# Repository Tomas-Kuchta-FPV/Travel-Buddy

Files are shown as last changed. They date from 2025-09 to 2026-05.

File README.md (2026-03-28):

# Travel-Buddy
Pocketable, smart and sleek Meshtastic node. With keyboard, Eink screen, GPS and all day baterry life thanks to it's Solar panel. Based on the [Seed Studio Wio tracker L1](https://meshtastic.org/docs/hardware/devices/seeed-studio/wio-series/tracker-l1/).  

Took inspiration from the original idea of Meshtastic and made a hiker, prepper and EDC friendly device.  

## Specifications
- **Wio tracker L1 Eink** a nifty main board
    - **GPS** to know where you and your frinds are
    - **nRF52840** to sip power bit by bit
    - **2.3 Inch Eink screen** so you never miss anything 
    - **Navigation buttons** for easy and intuitive control
    - **On-Off button** to save power for when the Sun is hiding
    - **Antenna** the default antenna is pretty good
- [3x4 Nokia style](https://en.wikipedia.org/wiki/T9_%28predictive_text%29) keyboard for easy texting
- **Solar panel** so your battery can be rechargerd from 0 to 100 in just two daays
- Space for a **big battery** for the days when the sun isn't shining

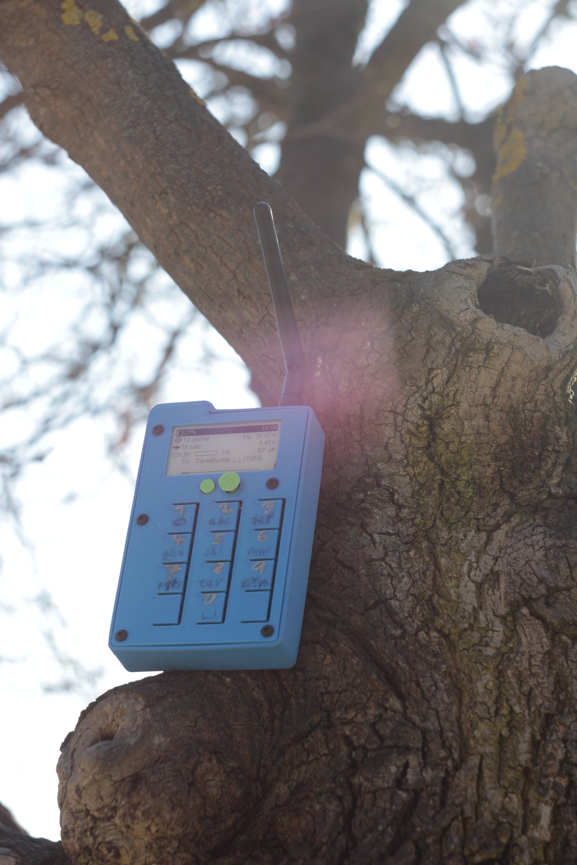
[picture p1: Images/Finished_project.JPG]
Finished Project


| Front | Back |
| --- | --- |
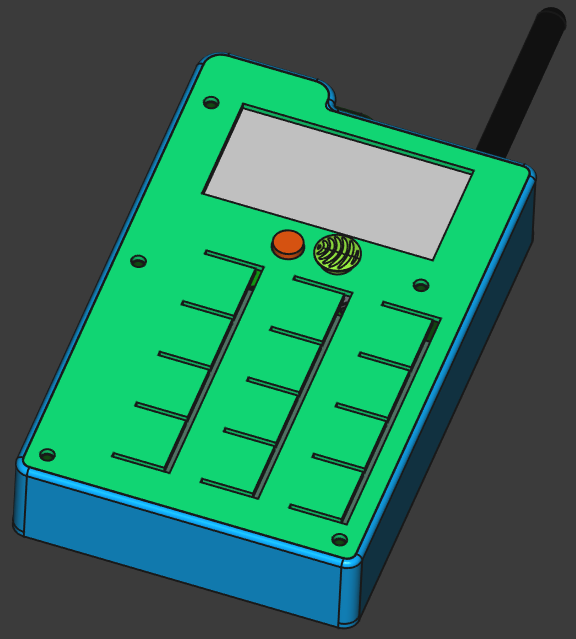
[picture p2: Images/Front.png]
front
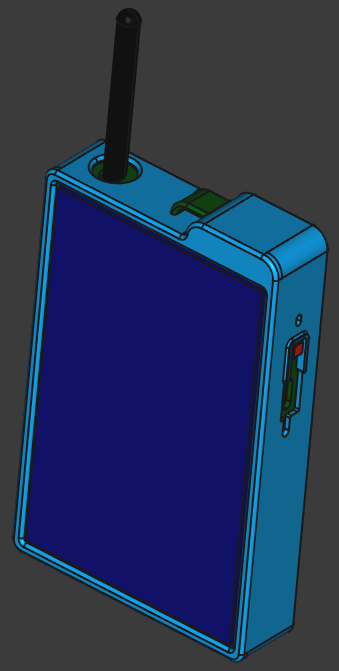
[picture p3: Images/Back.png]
back
|  |  |

## Use cases
Built for hikers, makers, preppers, and everyday carry adventurers who like their tech smart, tough, and a little bit magical.

**Hikers** can wander freely without worrying about battery life, coverage, or fragile screens. Solar charging keeps it alive on long trails, GPS keeps you oriented, and Meshtastic keeps you connected with your group even when civilization politely vanishes. The only real responsibility is remembering to bring it along. 😅

**Makers** will feel right at home. It’s open-source, hackable, and begging to be customized. New firmware ideas, experimental features, clever power optimizations. This thing is a playground for curious minds who like to bend hardware to their will.

**Preppers** get a resilient, low-power communication tool that keeps working when the grid doesn’t. Solar charging, long battery life, offline mesh networking, and the ability to tinker and repair make it a quiet little survival ally that doesn’t ask for much.

**EDC** enthusiasts get a pocketable device that just works. No constant charging anxiety, no fragile glass screens, no babysitting. Toss it in your bag or clip it to your gear and let it quietly do its job, day after day, powered by sunlight and good engineering dreams.

| Top | Front | PCB |
| --- | --- | --- |
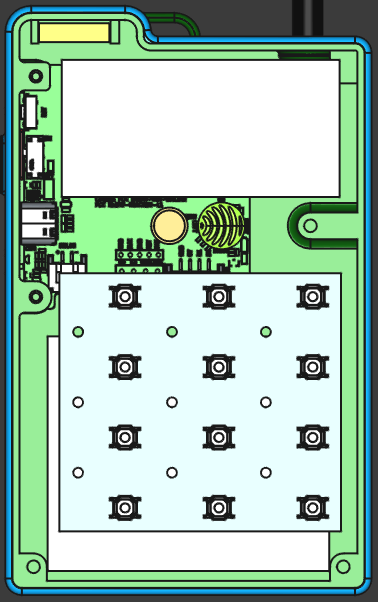
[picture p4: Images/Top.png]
Top
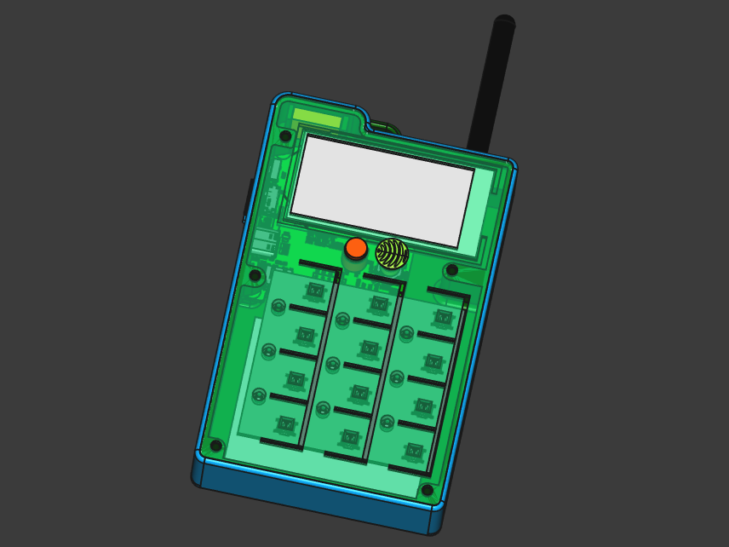
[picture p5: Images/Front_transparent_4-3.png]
Front_trans
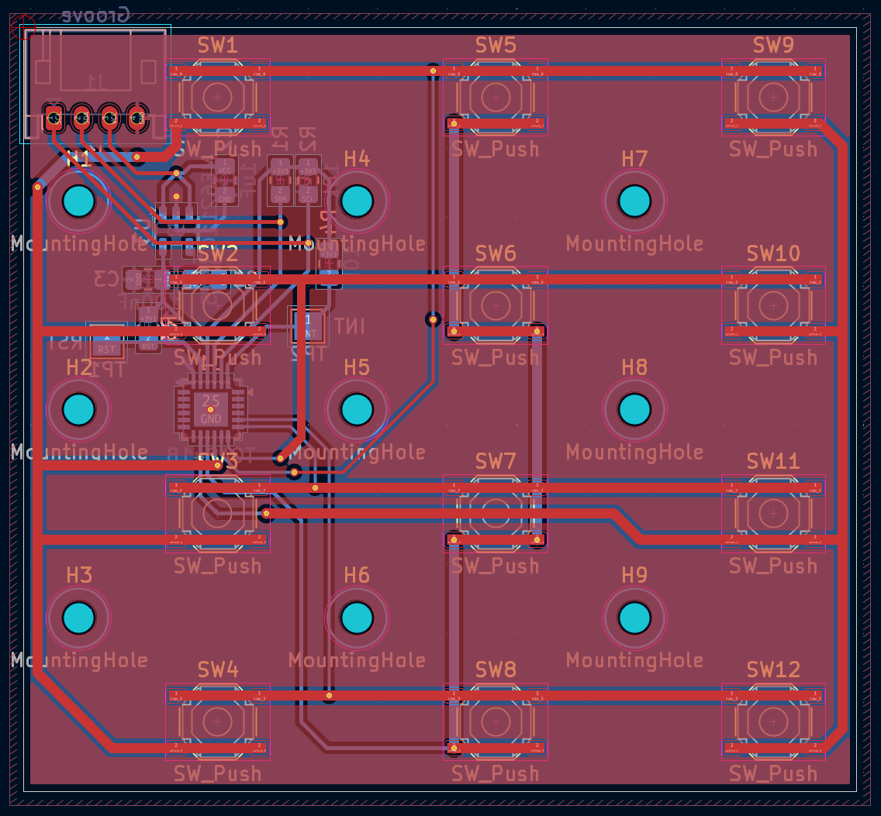
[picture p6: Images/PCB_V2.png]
PCB_screen
|  |  |  |

## My motivation to build it
It is some sort of challange to see wether I can do a project thar can be comercialized, almost evhery project can end up making some money but many times it depends wether its worth it.  
I have way more faith when I built the physical prototype as it seems like a super cool and handy idea.  
And also it's a whole lot of fun to do a project that doesn't need to worry about money or the general public. ;)

## BOM
[BOM.ods](/BOM.ods)

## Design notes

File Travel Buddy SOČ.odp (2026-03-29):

## Travel buddy

All in one meshtastic komunikátor

By Tomáš Kuchta

## Začněme nejdřív u projektu meshtastic

- Jedná se o decentralizovaný komunikační projekt na základě LoRa rádií
- Nejčastější je posílání krátkých textových zpráv
- Ale dají se posílat i data ze senzorů
- Energeticky nenáročný provoz v řádě miliwat
  - Dokáže se napájet ze solárního panelu

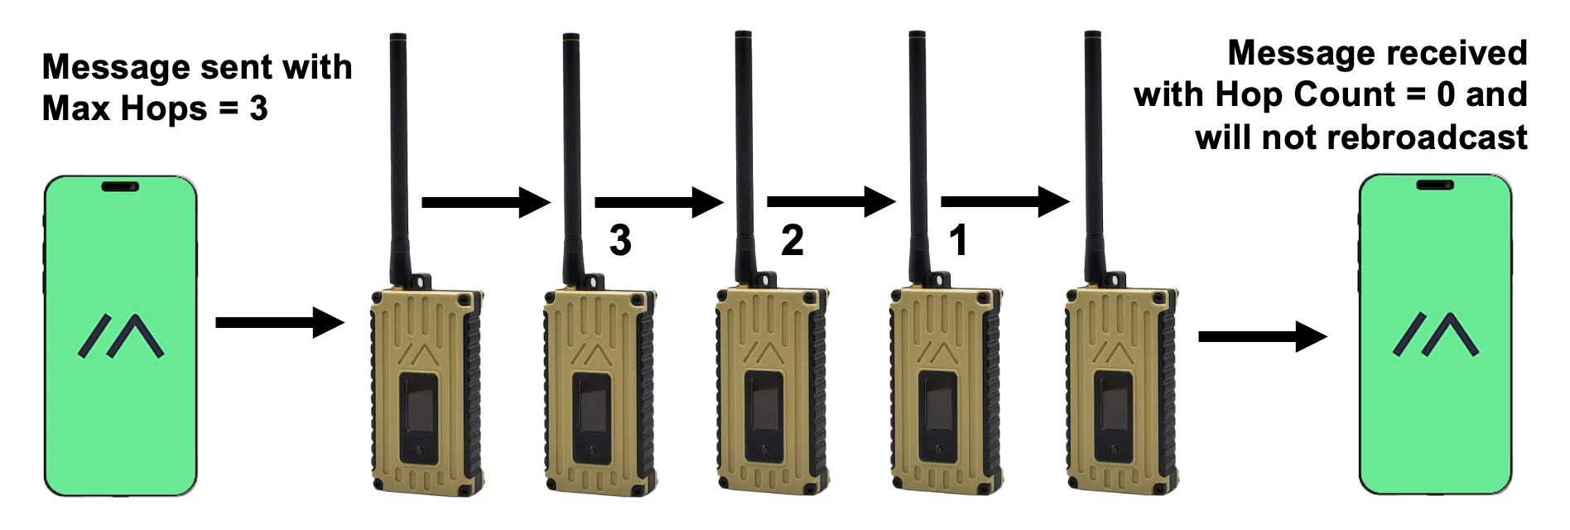
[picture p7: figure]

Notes: Používá se třeba při výpadku sítí nebo v místech bez telefoního signálu

## Uživatelské zařízení

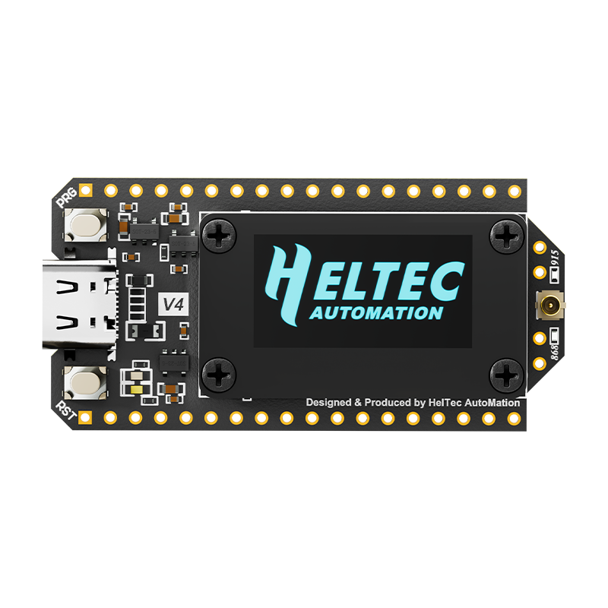
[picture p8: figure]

- Většinou obsahují
  - MCU
  - LoRA modem
  - Obrazovku
- A většina uživatelského vstupu se děje v mobilní aplikaci

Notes: Což to není úplně ono pro off grid komunikaci
OR Toto řešení není ideální pro off-grid použití

## A proto jsem navrhnul Travel Buddy

- Unikátní kompletní řešení pro meshtastic textovou komunikaci

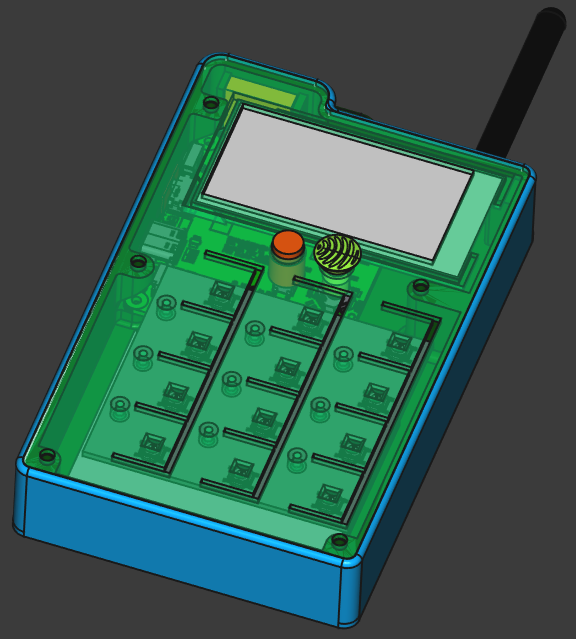
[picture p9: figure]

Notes: Výstup je realizován pomocí Eink obrazovky A vstup navigačním tlačítkem
a revoluční Nokia telefoní klávesničkou

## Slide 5

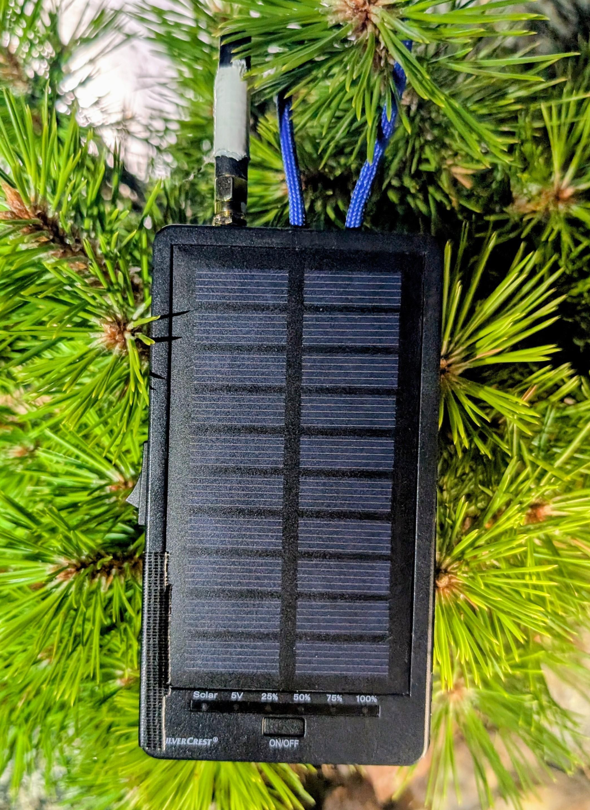
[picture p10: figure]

## Mé další nápady pro využití meshtasticku

- Přístupný sledovací systém pro psi
- Monitotorování ptačí populace
- Monitorování ovzduší
- Monitorování koncentrace CO2 v místnosti

## Zdroje

- heltec.org (https://heltec.org/project/wifi-lora-32-v4/)
- Meshtastic.org

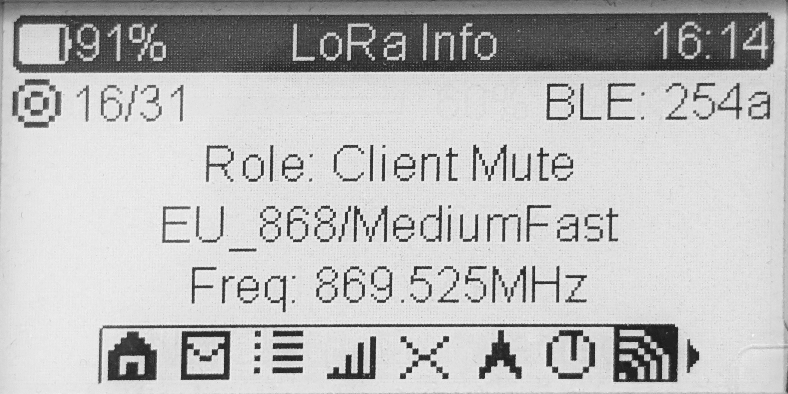
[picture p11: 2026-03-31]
Images/Screens 2.7.20/8_LoRa.jpg

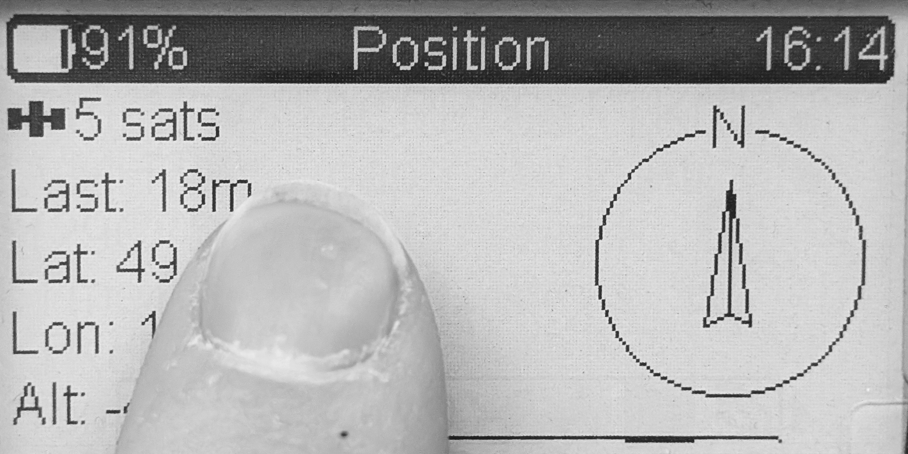
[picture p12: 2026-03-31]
Images/Screens 2.7.20/7_position.jpg

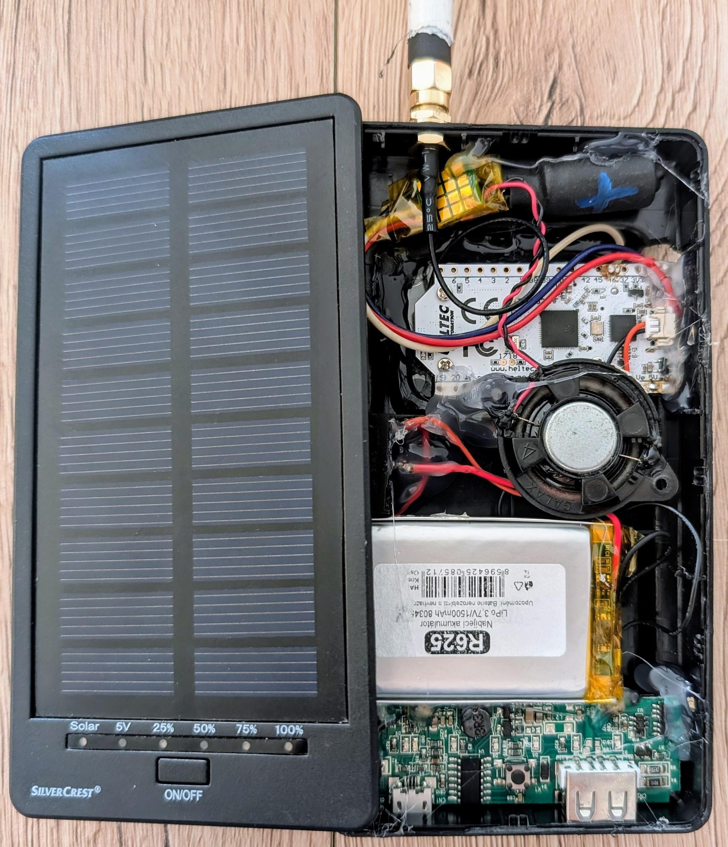
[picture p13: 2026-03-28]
Images/Prototype_Front-opened.jpg

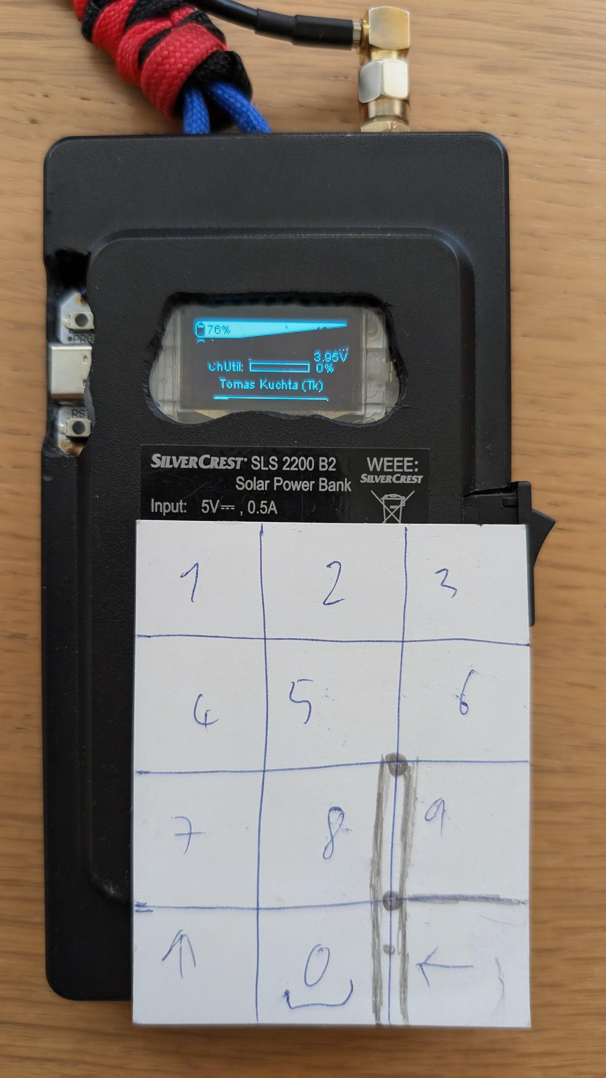
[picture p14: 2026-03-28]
Images/Keyboard Prototype.jpg

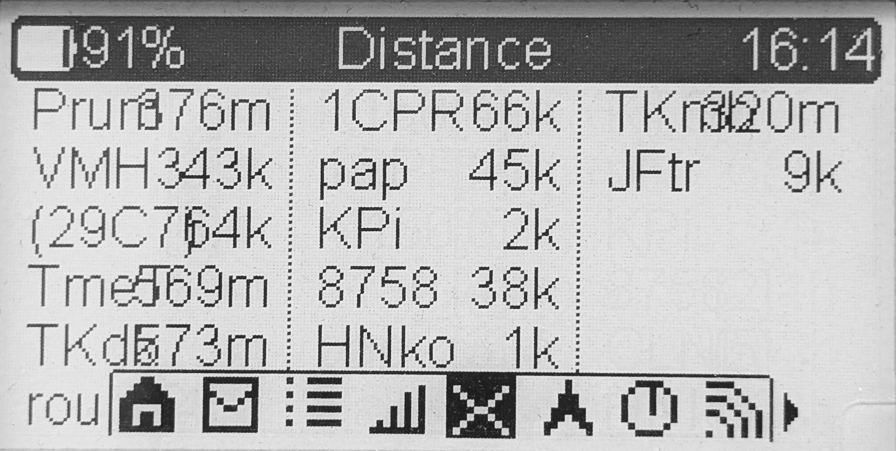
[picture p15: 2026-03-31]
Images/Screens 2.7.20/5_distance.jpg

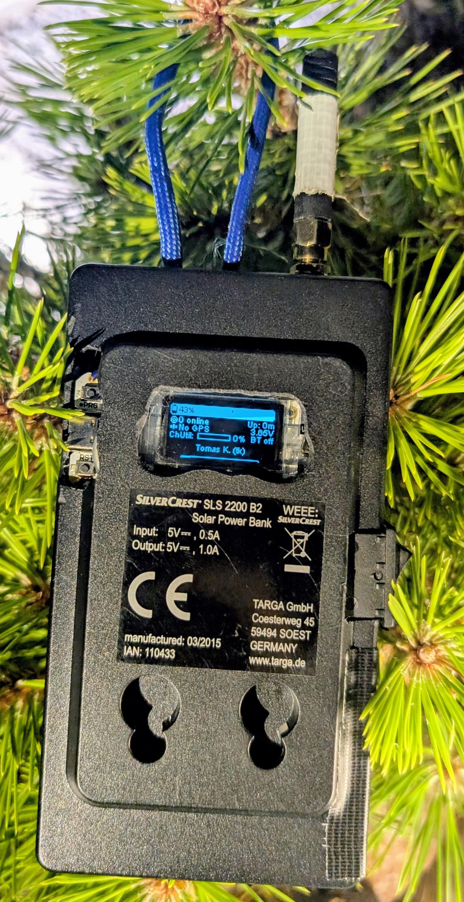
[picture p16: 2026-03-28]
Images/Prototype_Back.jpg

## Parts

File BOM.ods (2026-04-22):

EUR → USD |  | 1.17 |  | Notes
Item | Qty | Price (USD) | Link |  | Alternative link | Description
Wio tracker L1 Eink | 1 | $32.75 | https://www.seeedstudio.com/Wio-Tracker-L1-E-ink-p-6456.html
~ Seed studio EU VAT + shipping | 1 | $19.36
Subtotal |  | $52.11
~ 3D printed parts | 1 | ~ $5
Plexiglas to cover the screen and PV | 1
Bare PCB | 1 | $4.00 | /4x3 keyboard/production/3x4_Keyboard_V2.zip
JLCPCB EU VAT + shipping | 1 | $1.50
Subtotal |  | $5.50
M2x4 flathead | 5 | $1.05 | https://www.aliexpress.com/item/1005006738242477.html | For the keyboard
M2x6 | 4 | $1.05 | https://www.aliexpress.com/item/1005006738242477.html | For the wio. Or you can use M2x4
M3x6 | 6 | $1.50 | https://www.aliexpress.com/item/32810852732.html | For the shell
Subtotal |  | $3.60
Passives | - | $0.50 | The full list is in PCB BOM
TCA8418RTWR | 1 | $0.57 | https://www.lcsc.com/product-detail/C138713.html |  | https://www.aliexpress.com/item/33026225094.html | I2C keyboard matrix
ME6211C33M5G | 1 | $0.05 | https://www.lcsc.com/product-detail/C82942.html |  | https://www.aliexpress.com/item/1005008748602232.html | 3.3V Positive Fixed SOT-23-5 LDO
TS-1187A-B-A-B | 12 | $0.22 | https://www.lcsc.com/product-detail/C318884.html |  | https://www.aliexpress.com/item/1005008182839695.html Color: No.1 | Tactile Switch SPST 160gf 1.5mm 5.1mm x 5.1mm Surface Mount
S4B-PH-K-S(LF)(SN) | 1 | $0.05 | https://www.lcsc.com/product-detail/C157926.html |  | https://www.aliexpress.com/item/33053313994.html Pins: 4P | 4 position 2mm Pitch 2A Right Angle
LCSC Shipping | - | $15.89
Subtotal |  | $17.28
5V Solar panel 69x110 | 1 | $3.59 | https://www.aliexpress.com/item/1005009205739856.html Color: 1.2W 5V |  | https://www.aliexpress.com/item/32906698984.html
Battery |  | $11.22 | https://www.aliexpress.com/item/1005010642051383.html |  |  | max. H<58mm, W<72mm, T<12mm
1.0mm 2p JST for the baterry |  | $1.10 | https://www.aliexpress.com/item/1005006016256124.html | Mind the polarity, Or use the included adapter
Groove cable |  | $3.51 | https://www.seeedstudio.com/Grove-Universal-4-Pin-20cm-Unbuckled-Cable-5-PCs-Pack-p-749.html | They are using their own connector | https://shop.m5stack.com/products/4pin-buckled-grove-cable Or a modified SH2.0 also works
Subtotal |  | $19.42
Total |  | $97.91

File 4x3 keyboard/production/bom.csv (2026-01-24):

Designator | Footprint | Quantity | Value | LCSC Part #
C1, C2 | 0805 | 2 | 1uF | C28323
C3 | 0805 | 1 | 100nF | C49678
J1 | JST_PH_S4B-PH-K_1x04_P2.00mm_Horizontal | 1 | Groove | C157926
R1, R2, R3, R4 | 0805 | 4 | 10k | 0805
SW1, SW10, SW11, SW12, SW2, SW3, SW4, SW5, SW6, SW7, SW8, SW9 | SW_Push_1P1T_XKB_TS-1187A | 12 | SW_Push | C318884
TP1 | TestPoint_Pad_2.0x2.0mm | 1 | RST
TP2 | TestPoint_Pad_2.0x2.0mm | 1 | INT
U1 | WQFN-24-1EP_4x4mm_P0.5mm_EP2.45x2.45mm | 1 | TCA8418 | C138713
U3 | SOT-23-5 | 1 | ME6211C33M5 | C82942

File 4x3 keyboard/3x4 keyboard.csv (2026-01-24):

Reference | Qty | LCSC | Value | Footprint | Datasheet
C1,C2 | 2 | C28323 | 1uF | Capacitor_SMD:C_0805_2012Metric_Pad1.18x1.45mm_HandSolder | ~
C3 | 1 | C49678 | 100nF | Capacitor_SMD:C_0805_2012Metric_Pad1.18x1.45mm_HandSolder | ~
J1 | 1 | C157926 | Groove | Connector_JST:JST_PH_S4B-PH-K_1x04_P2.00mm_Horizontal | ~
R1,R2,R3,R4 | 4 | 0805 | 10k | Resistor_SMD:R_0805_2012Metric_Pad1.20x1.40mm_HandSolder | ~
SW1,SW2,SW3,SW4,SW5,SW6,SW7,SW8,SW9,SW10,SW11,SW12 | 12 | C318884 | SW_Push | Button_Switch_SMD:SW_Push_1P1T_XKB_TS-1187A | ~
TP1 | 1 |  | RST | TestPoint:TestPoint_Pad_2.0x2.0mm | ~
TP2 | 1 |  | INT | TestPoint:TestPoint_Pad_2.0x2.0mm | ~
U1 | 1 | C138713 | TCA8418 | Package_DFN_QFN:WQFN-24-1EP_4x4mm_P0.5mm_EP2.45x2.45mm | https://www.ti.com/lit/ds/symlink/tca8418.pdf?ts=1768477131536
U2 | 1 | C2875118 | MCP1700x-330xxTT | Package_TO_SOT_SMD:SOT-23 | http://ww1.microchip.com/downloads/en/DeviceDoc/20001826D.pdf

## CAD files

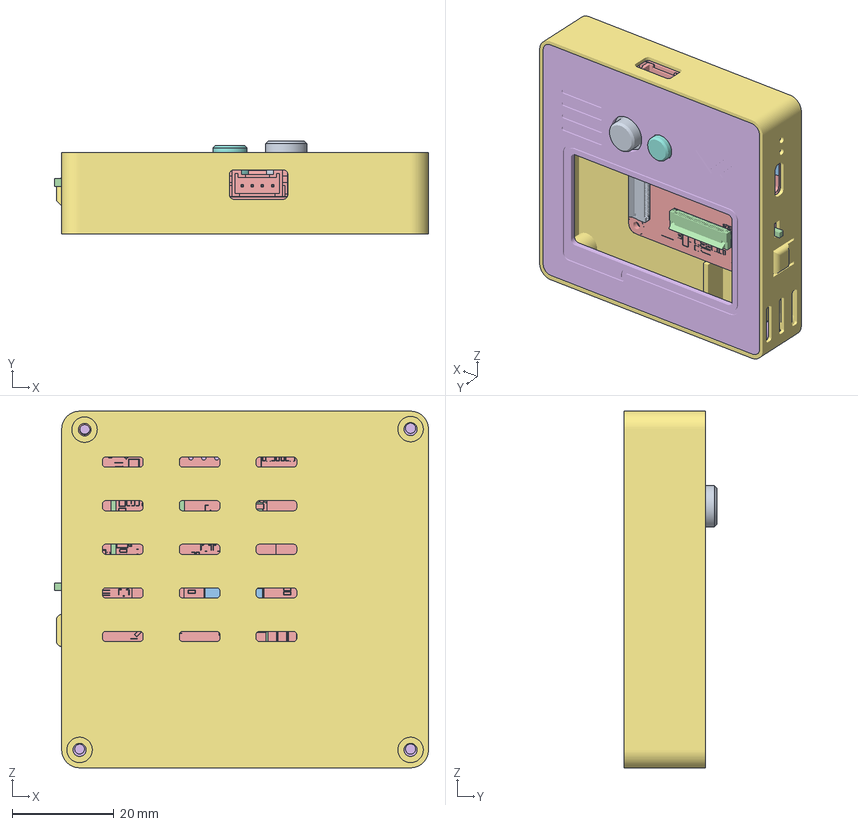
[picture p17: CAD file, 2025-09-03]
References/case-asembly_wio-tracker-L1-E-ink.FCStd
73.4 x 18.3 x 70.0 mm
FPC0_5K-DH-24PWB
MESHTASTIC_REPEATER_HANDLE_1__1
MESHTASTIC_REPEATER_HANDLE_1__2
FPC0_5K-DH-30PWB
MESHTASTIC_REPEATER_HANDLE_1__3
MESHTASTIC_REPEATER_HANDLE_1__4
MESHTASTIC_REPEATER_HANDLE_1__5
MESHTASTIC_REPEATER_HANDLE_1__6
MESHTASTIC_REPEATER_HANDLE_1__7
MESHTASTIC_REPEATER_HANDLE_1__8
MESHTASTIC_REPEATER_HANDLE_1__9
MESHTASTIC_REPEATER_HANDLE_1_10
MESHTASTIC_REPEATER_HANDLE_1_11
MESHTASTIC_REPEATER_HANDLE_1_12
MESHTASTIC_REPEATER_HANDLE_1_13
MESHTASTIC_REPEATER_HANDLE_1_14
MESHTASTIC_REPEATER_HANDLE_1_15
MESHTASTIC_REPEATER_HANDLE_1_16
MESHTASTIC_REPEATER_HANDLE_1_17
MESHTASTIC_REPEATER_HANDLE_1_18
MESHTASTIC_REPEATER_HANDLE_1_19
MESHTASTIC_REPEATER_HANDLE_1_20
MESHTASTIC_REPEATER_HANDLE_1_22
MESHTASTIC_REPEATER_HANDLE_1_24
MESHTASTIC_REPEATER_HANDLE_1_25
MESHTASTIC_REPEATER_HANDLE_1_26
MESHTASTIC_REPEATER_HANDLE_1_27
MESHTASTIC_REPEATER_HANDLE_1_28
MESHTASTIC_REPEATER_HANDLE_1_29
MESHTASTIC_REPEATER_HANDLE_1_30
MESHTASTIC_REPEATER_HANDLE_1_31
MESHTASTIC_REPEATER_HANDLE_1_32
MESHTASTIC_REPEATER_HANDLE_1_33
USB_C_RECEPTACLE_GCT_USB4105-_1
USB_C_RECEPTACLE_GCT_USB4105-_2
USB_C_RECEPTACLE_GCT_USB4105-_3
USB_C_RECEPTACLE_GCT_USB4105-_4
USB_C_RECEPTACLE_GCT_USB4105-_5
USB_C_RECEPTACLE_GCT_USB4105-_6
USB_C_RECEPTACLE_GCT_USB4105-_7
USB_C_RECEPTACLE_GCT_USB4105-_8
USB_C_RECEPTACLE_GCT_USB4105-_9
USB_C_RECEPTACLE_GCT_USB4105_10
USB_C_RECEPTACLE_GCT_USB4105_11
USB_C_RECEPTACLE_GCT_USB4105_12
USB_C_RECEPTACLE_GCT_USB4105_13
USB_C_RECEPTACLE_GCT_USB4105_14
USB_C_RECEPTACLE_GCT_USB4105_15
USB_C_RECEPTACLE_GCT_USB4105_16
USB_C_RECEPTACLE_GCT_USB4105_17
USB_C_RECEPTACLE_GCT_USB4105_18
USB_C_RECEPTACLE_GCT_USB4105_19
USB_C_RECEPTACLE_GCT_USB4105_20
USB_C_RECEPTACLE_GCT_USB4105_21
USB_C_RECEPTACLE_GCT_USB4105_22
USB_C_RECEPTACLE_GCT_USB4105_23
USB_C_RECEPTACLE_GCT_USB4105_24
USB_C_RECEPTACLE_GCT_USB4105_25
USB_C_RECEPTACLE_GCT_USB4105_26
USB_C_RECEPTACLE_GCT_USB4105_27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

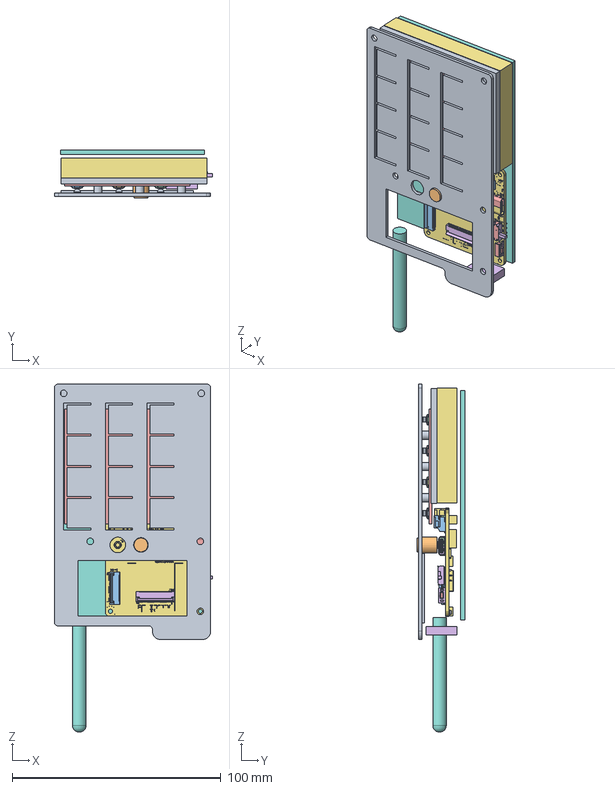
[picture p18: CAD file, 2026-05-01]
Travel_buddy_V1.1.FCStd
76.0 x 23.0 x 166.8 mm
LID
Menu BTN
FPC0_5K-DH-24PWB
MESHTASTIC_REPEATER_HANDLE_1__1
MESHTASTIC_REPEATER_HANDLE_1__2
FPC0_5K-DH-30PWB
MESHTASTIC_REPEATER_HANDLE_1__3
MESHTASTIC_REPEATER_HANDLE_1__4
MESHTASTIC_REPEATER_HANDLE_1__5
MESHTASTIC_REPEATER_HANDLE_1__6
MESHTASTIC_REPEATER_HANDLE_1__7
MESHTASTIC_REPEATER_HANDLE_1__8
MESHTASTIC_REPEATER_HANDLE_1__9
MESHTASTIC_REPEATER_HANDLE_1_10
MESHTASTIC_REPEATER_HANDLE_1_11
MESHTASTIC_REPEATER_HANDLE_1_12
MESHTASTIC_REPEATER_HANDLE_1_13
MESHTASTIC_REPEATER_HANDLE_1_14
MESHTASTIC_REPEATER_HANDLE_1_15
MESHTASTIC_REPEATER_HANDLE_1_16
MESHTASTIC_REPEATER_HANDLE_1_17
MESHTASTIC_REPEATER_HANDLE_1_18
MESHTASTIC_REPEATER_HANDLE_1_19
MESHTASTIC_REPEATER_HANDLE_1_20
MESHTASTIC_REPEATER_HANDLE_1_22
MESHTASTIC_REPEATER_HANDLE_1_24
MESHTASTIC_REPEATER_HANDLE_1_25
MESHTASTIC_REPEATER_HANDLE_1_26
MESHTASTIC_REPEATER_HANDLE_1_27
MESHTASTIC_REPEATER_HANDLE_1_28
MESHTASTIC_REPEATER_HANDLE_1_29
MESHTASTIC_REPEATER_HANDLE_1_30
MESHTASTIC_REPEATER_HANDLE_1_31
MESHTASTIC_REPEATER_HANDLE_1_32
MESHTASTIC_REPEATER_HANDLE_1_33
USB_C_RECEPTACLE_GCT_USB4105-_1
USB_C_RECEPTACLE_GCT_USB4105-_2
USB_C_RECEPTACLE_GCT_USB4105-_3
USB_C_RECEPTACLE_GCT_USB4105-_4
USB_C_RECEPTACLE_GCT_USB4105-_5
USB_C_RECEPTACLE_GCT_USB4105-_6
USB_C_RECEPTACLE_GCT_USB4105-_7
USB_C_RECEPTACLE_GCT_USB4105-_8
USB_C_RECEPTACLE_GCT_USB4105-_9
USB_C_RECEPTACLE_GCT_USB4105_10
USB_C_RECEPTACLE_GCT_USB4105_11
USB_C_RECEPTACLE_GCT_USB4105_12
USB_C_RECEPTACLE_GCT_USB4105_13
USB_C_RECEPTACLE_GCT_USB4105_14
USB_C_RECEPTACLE_GCT_USB4105_15
USB_C_RECEPTACLE_GCT_USB4105_16
USB_C_RECEPTACLE_GCT_USB4105_17
USB_C_RECEPTACLE_GCT_USB4105_18
USB_C_RECEPTACLE_GCT_USB4105_19
USB_C_RECEPTACLE_GCT_USB4105_20
USB_C_RECEPTACLE_GCT_USB4105_21
USB_C_RECEPTACLE_GCT_USB4105_22
USB_C_RECEPTACLE_GCT_USB4105_23
USB_C_RECEPTACLE_GCT_USB4105_24
USB_C_RECEPTACLE_GCT_USB4105_25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

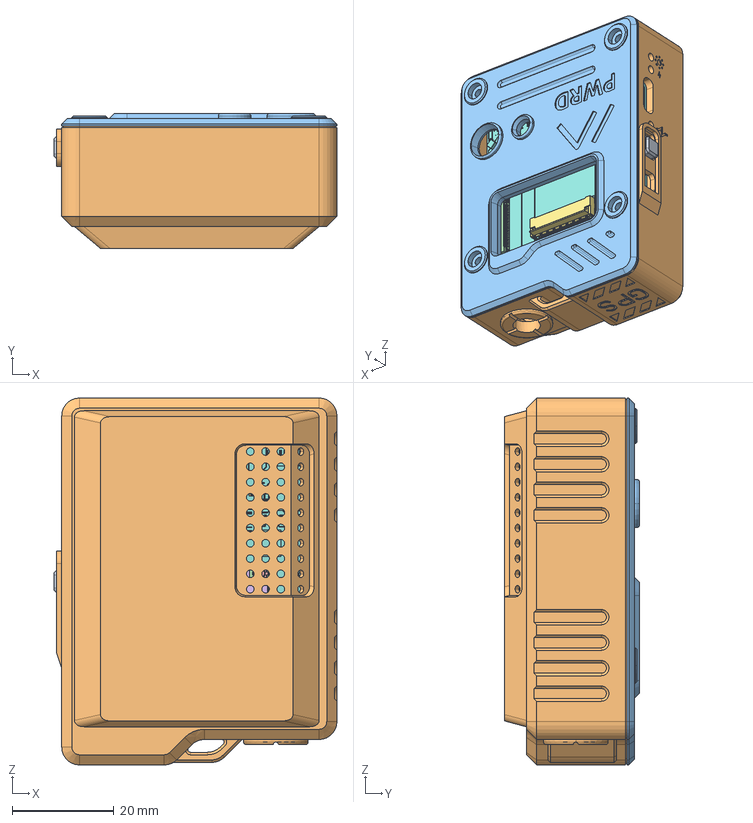
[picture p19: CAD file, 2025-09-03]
References/case-asembly_wio-tracker-L1-OLED.FCStd
55.5 x 26.5 x 72.0 mm
1-A2
DOWN
UP
FPC0_5K-DH-24PWB
MESHTASTIC_REPEATER_HANDLE_1__1
MESHTASTIC_REPEATER_HANDLE_1__2
FPC0_5K-DH-30PWB
MESHTASTIC_REPEATER_HANDLE_1__3
MESHTASTIC_REPEATER_HANDLE_1__4
MESHTASTIC_REPEATER_HANDLE_1__5
MESHTASTIC_REPEATER_HANDLE_1__6
MESHTASTIC_REPEATER_HANDLE_1__7
MESHTASTIC_REPEATER_HANDLE_1__8
MESHTASTIC_REPEATER_HANDLE_1__9
MESHTASTIC_REPEATER_HANDLE_1_10
MESHTASTIC_REPEATER_HANDLE_1_11
MESHTASTIC_REPEATER_HANDLE_1_12
MESHTASTIC_REPEATER_HANDLE_1_13
MESHTASTIC_REPEATER_HANDLE_1_14
MESHTASTIC_REPEATER_HANDLE_1_15
MESHTASTIC_REPEATER_HANDLE_1_16
MESHTASTIC_REPEATER_HANDLE_1_17
MESHTASTIC_REPEATER_HANDLE_1_18
MESHTASTIC_REPEATER_HANDLE_1_19
MESHTASTIC_REPEATER_HANDLE_1_20
MESHTASTIC_REPEATER_HANDLE_1_22
MESHTASTIC_REPEATER_HANDLE_1_24
MESHTASTIC_REPEATER_HANDLE_1_25
MESHTASTIC_REPEATER_HANDLE_1_26
MESHTASTIC_REPEATER_HANDLE_1_27
MESHTASTIC_REPEATER_HANDLE_1_28
MESHTASTIC_REPEATER_HANDLE_1_29
MESHTASTIC_REPEATER_HANDLE_1_30
MESHTASTIC_REPEATER_HANDLE_1_31
MESHTASTIC_REPEATER_HANDLE_1_32
MESHTASTIC_REPEATER_HANDLE_1_33
USB_C_RECEPTACLE_GCT_USB4105-_1
USB_C_RECEPTACLE_GCT_USB4105-_2
USB_C_RECEPTACLE_GCT_USB4105-_3
USB_C_RECEPTACLE_GCT_USB4105-_4
USB_C_RECEPTACLE_GCT_USB4105-_5
USB_C_RECEPTACLE_GCT_USB4105-_6
USB_C_RECEPTACLE_GCT_USB4105-_7
USB_C_RECEPTACLE_GCT_USB4105-_8
USB_C_RECEPTACLE_GCT_USB4105-_9
USB_C_RECEPTACLE_GCT_USB4105_10
USB_C_RECEPTACLE_GCT_USB4105_11
USB_C_RECEPTACLE_GCT_USB4105_12
USB_C_RECEPTACLE_GCT_USB4105_13
USB_C_RECEPTACLE_GCT_USB4105_14
USB_C_RECEPTACLE_GCT_USB4105_15
USB_C_RECEPTACLE_GCT_USB4105_16
USB_C_RECEPTACLE_GCT_USB4105_17
USB_C_RECEPTACLE_GCT_USB4105_18
USB_C_RECEPTACLE_GCT_USB4105_19
USB_C_RECEPTACLE_GCT_USB4105_20
USB_C_RECEPTACLE_GCT_USB4105_21
USB_C_RECEPTACLE_GCT_USB4105_22
USB_C_RECEPTACLE_GCT_USB4105_23
USB_C_RECEPTACLE_GCT_USB4105_24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

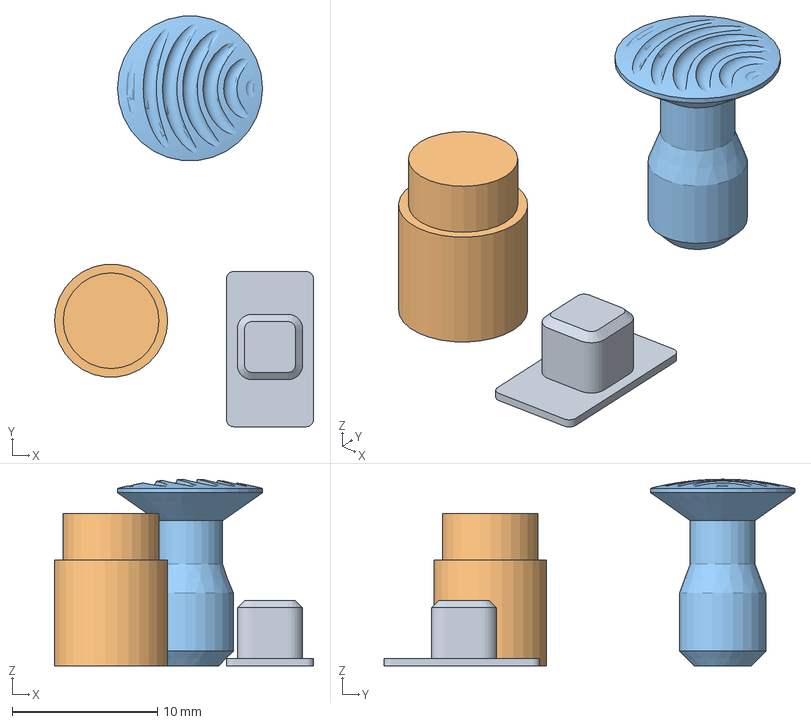
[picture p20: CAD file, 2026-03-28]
Travel_buddy_V1-case 2_of_3.3mf
17.8 x 28.3 x 12.9 mm
Travel_buddy_V1-case_4
Travel_buddy_V1-case_5
Travel_buddy_V1-case_6

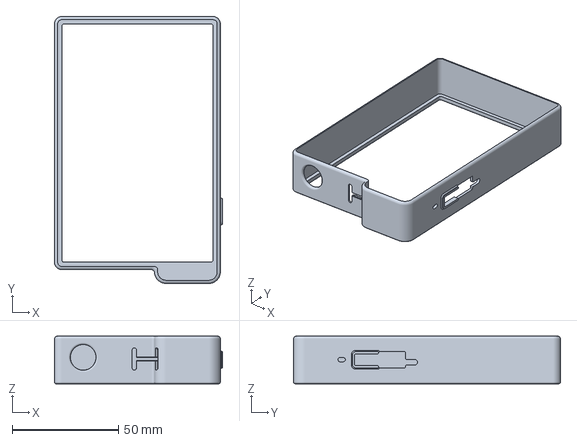
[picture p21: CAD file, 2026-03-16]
Travel_buddy_V1-case 3_of_3.3mf
79.0 x 125.5 x 22.5 mm

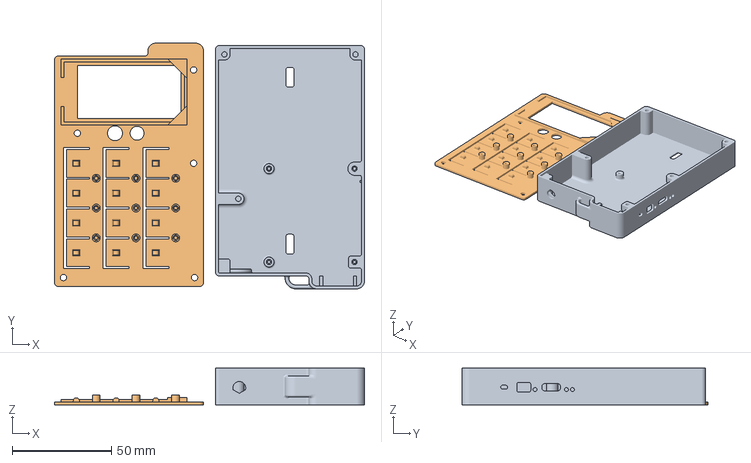
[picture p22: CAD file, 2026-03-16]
Travel_buddy_V1-case 1_of_3.3mf
156.0 x 123.7 x 18.5 mm
Travel_buddy_V1-case_1
Travel_buddy_V1-case_2

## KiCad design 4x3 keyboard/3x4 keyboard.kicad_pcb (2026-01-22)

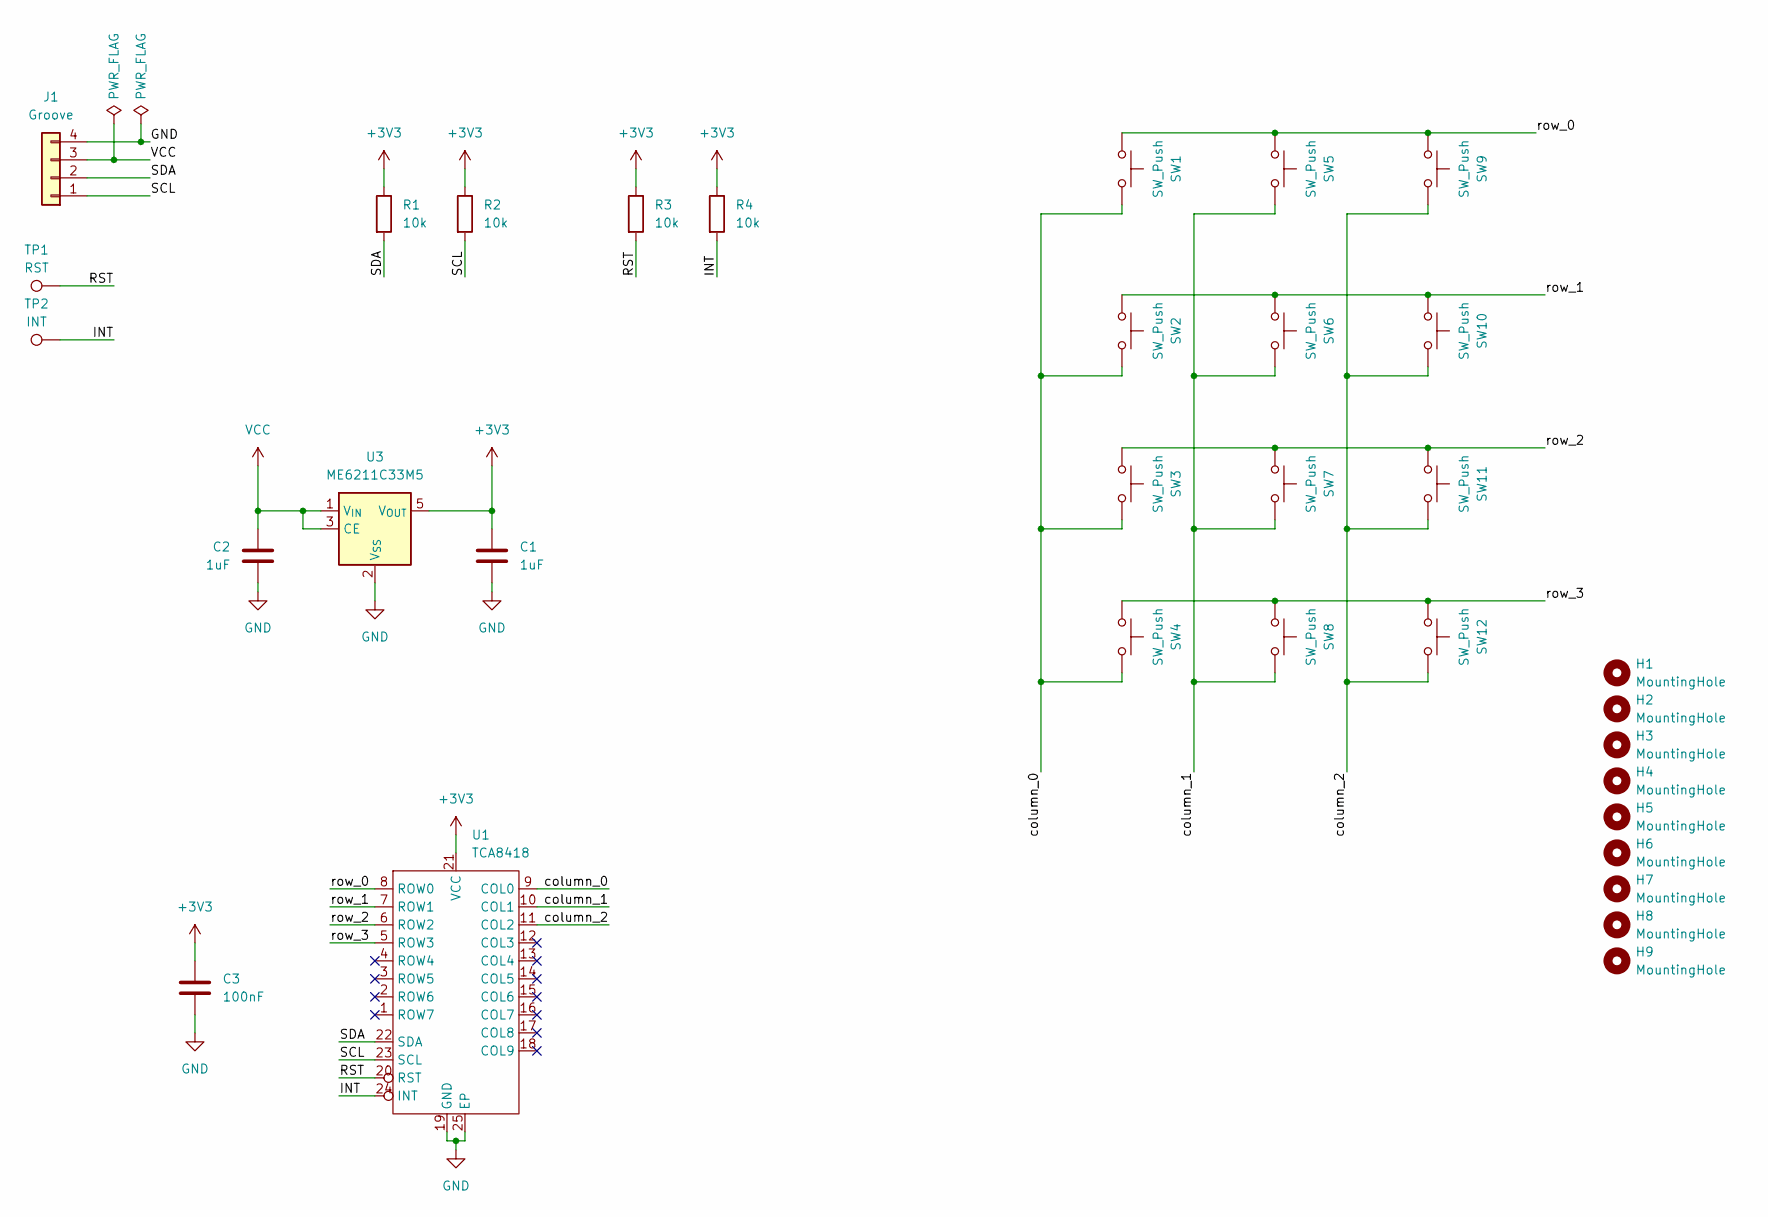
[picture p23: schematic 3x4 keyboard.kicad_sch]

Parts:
C1, C2: 1uF; C_0805_2012Metric_Pad1.18x1.45mm_HandSolder; LCSC C28323
C3: 100nF; C_0805_2012Metric_Pad1.18x1.45mm_HandSolder; LCSC C49678
H1, H2, H3, H4, H5, H6, H7, H8, H9: MountingHole; MountingHole_2.1mm
J1: Groove; JST_PH_S4B-PH-K_1x04_P2.00mm_Horizontal; LCSC C157926
R1, R2, R3, R4: 10k; R_0805_2012Metric_Pad1.20x1.40mm_HandSolder; LCSC 0805
SW1, SW2, SW3, SW4, SW5, SW6, SW7, SW8, SW9, SW10, SW11, SW12: SW_Push; SW_Push_1P1T_XKB_TS-1187A; LCSC C318884
TP1: RST; TestPoint_Pad_2.0x2.0mm
TP2: INT; TestPoint_Pad_2.0x2.0mm
U1: TCA8418; WQFN-24-1EP_4x4mm_P0.5mm_EP2.45x2.45mm; LCSC C138713
U3: ME6211C33M5; SOT-23-5; LCSC C82942

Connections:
+3V3: C1.1, C3.1, R1.1, R2.1, R3.1, R4.1, U1.21 (VCC), U3.5 (V_{OUT})
/INT: R4.2, TP2.1, U1.24 (INT)
/RST: R3.2, TP1.1, U1.20 (RST)
/SCL: J1.1, R2.2, U1.23 (SCL)
/SDA: J1.2, R1.2, U1.22 (SDA)
/column_0: SW1.2, SW2.2, SW3.2, SW4.2, U1.9 (COL0)
/column_1: SW5.2, SW6.2, SW7.2, SW8.2, U1.10 (COL1)
/column_2: SW9.2, SW10.2, SW11.2, SW12.2, U1.11 (COL2)
/row_0: SW1.1, SW5.1, SW9.1, U1.8 (ROW0)
/row_1: SW2.1, SW6.1, SW10.1, U1.7 (ROW1)
/row_2: SW3.1, SW7.1, SW11.1, U1.6 (ROW2)
/row_3: SW4.1, SW8.1, SW12.1, U1.5 (ROW3)
GND: C1.2, C2.2, C3.2, J1.4, U1.19 (GND), U1.25 (EP), U3.2 (V_{SS})
VCC: C2.1, J1.3, U3.1 (V_{IN}), U3.3 (CE)

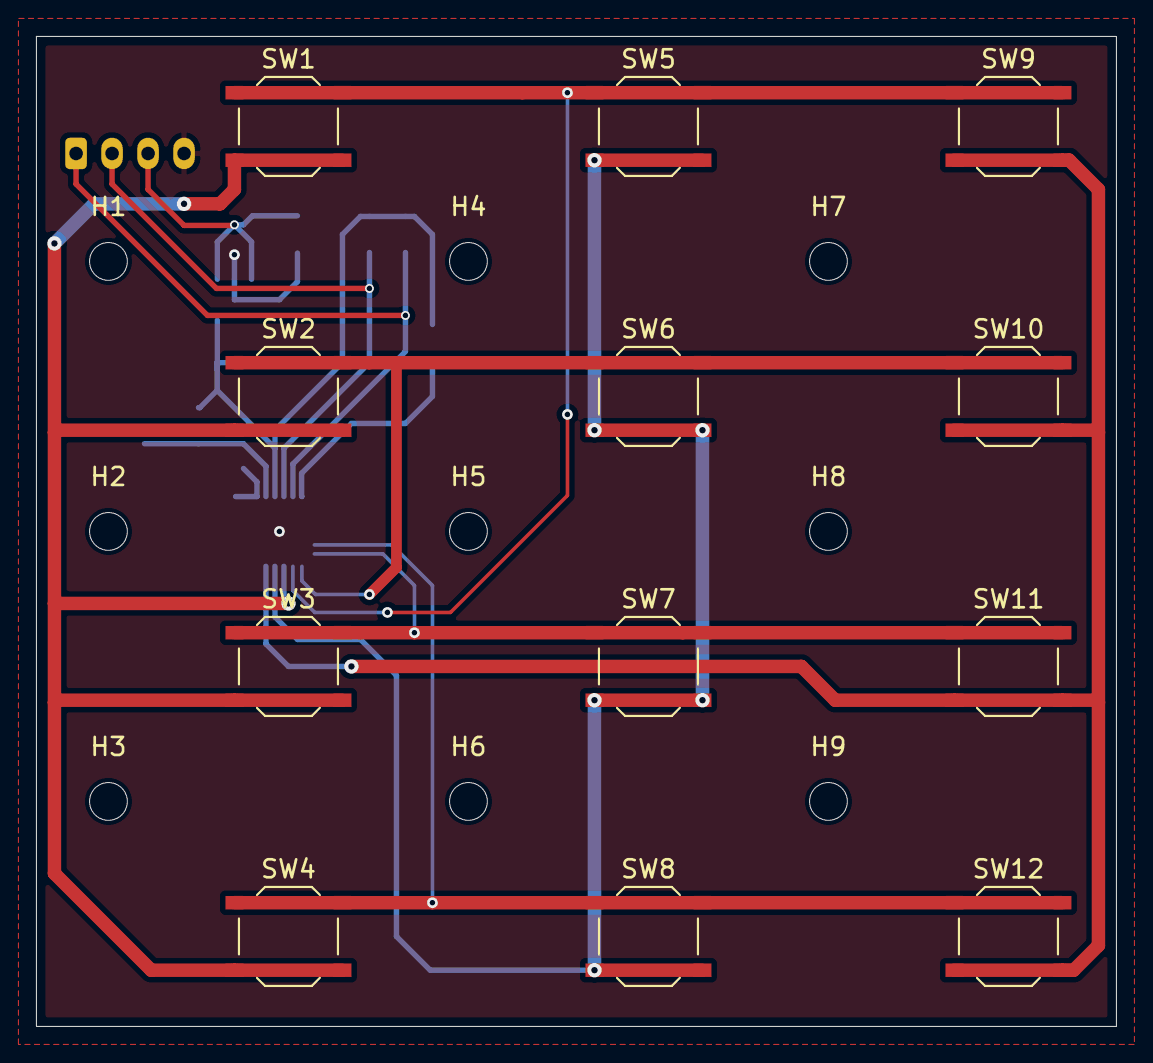
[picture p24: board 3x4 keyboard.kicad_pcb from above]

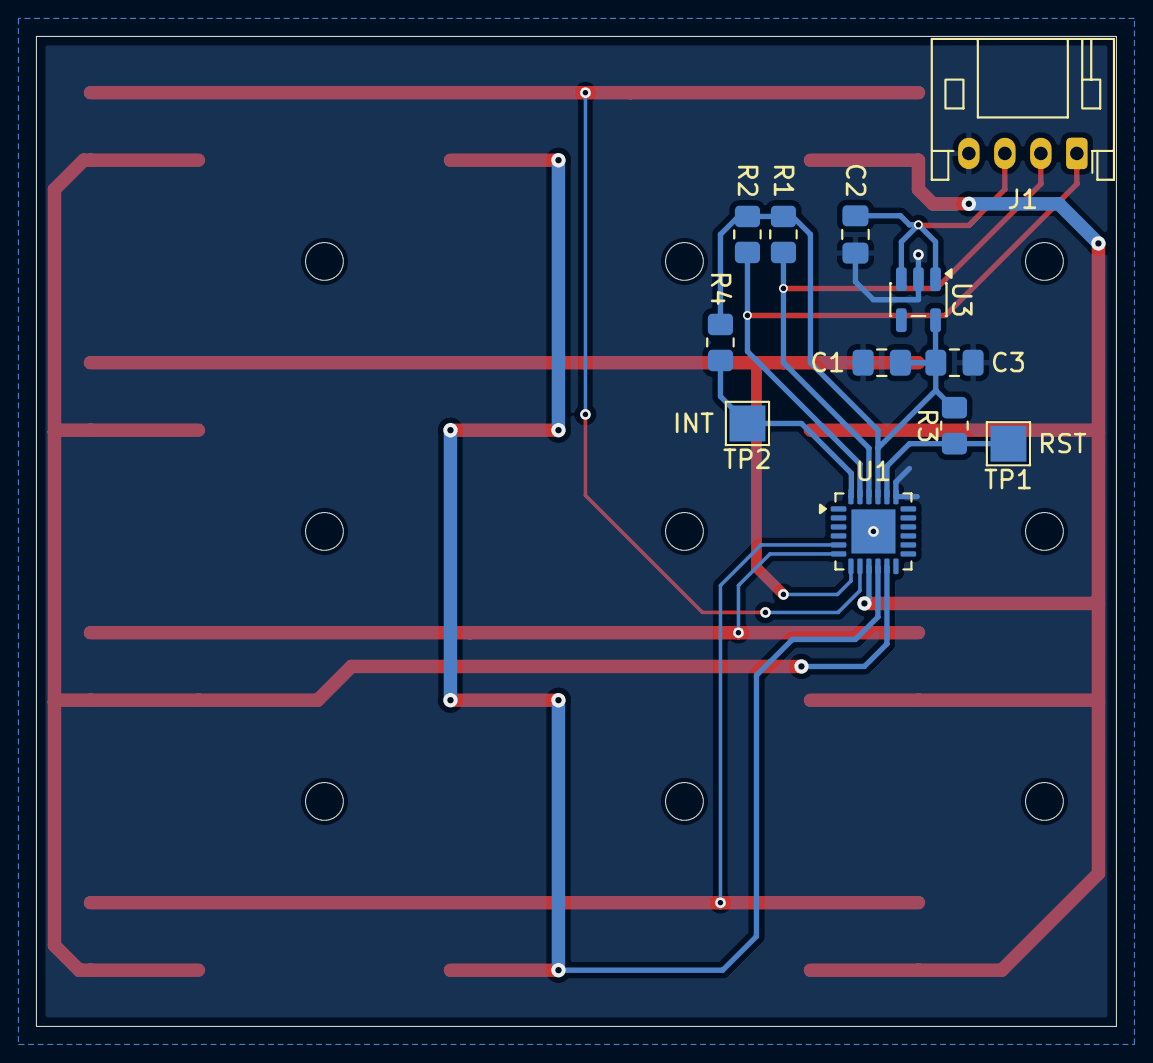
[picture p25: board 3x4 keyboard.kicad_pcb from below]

Board: 2 copper layers, 60.0 x 55.0 mm, 33 parts (12 on the bottom side), 14 nets.

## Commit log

2025-09-03 Added the project.
    [T9_keyboard-Choco_switches.step, T9_keyboard-MicroSwitches.step, T9_keyboard.kicad_pcb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]
2026-01-21 Finished the schematic
    [3x4 keyboard.kicad_pcb, 3x4 keyboard.kicad_sch, T9_keyboard-Choco_switches.step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]
2026-01-22 Finishing touches and a readme
    [3x4 keyboard.kicad_pcb, 3x4 keyboard.kicad_sch, BOM.ods]
2026-01-22 smoL fix
    [Travel_buddy_V1-case.step, Travel_buddy_V1.FCStd]
2026-01-24 Finish line!
    [3x4 keyboard.csv, BOM.csv, BOM.ods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]
2026-02-13 update step files
    [Travel_buddy_V1-case.3mf, Travel_buddy_V1.FCStd]
2026-03-07 Updated BOM for newer links and deduplicated BOMs.
    [BOM.csv, BOM.ods]
2026-03-16 updated 3d prints
    [Travel_buddy_V1-case 1_of_3.3mf, Travel_buddy_V1-case 2_of_3.3mf, Travel_buddy_V1-case 3_of_3.3mf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]
2026-03-28 finished the first prototype
    [Travel_buddy_V1-case 2_of_3.3mf, Travel_buddy_V1-case.step, case-asembly_wio-tracker-L1-E-ink.FCStd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]
2026-04-22 almost finisjed with the next wersion
    [BOM.ods, Travel_buddy_V1.1.FCStd, Travel_buddy_V1.FCStd]
2026-05-01 added labels!!
    [Travel_buddy_V1.1.FCStd]
